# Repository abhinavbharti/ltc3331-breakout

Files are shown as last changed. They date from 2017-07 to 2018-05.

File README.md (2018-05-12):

## Open, low-cost experimentation board for the LTC3331 energy harvesting chip
	
This project contains design- and production-files for a
low-cost LTC3331 energy harvesting development-, breakout- and test-board.

It's specifically designed to be inexpensive, yet open and comprehensive:
* Full design files for KiCad EDA
* 10cm x 10cm PCB with 2 layers
* Full pin breakout
* Less-comprehensive headers for pins usually required
* LIR2032 holder and alternative battery port
* All default options can be jumpered on or off
* Supercap pads provided

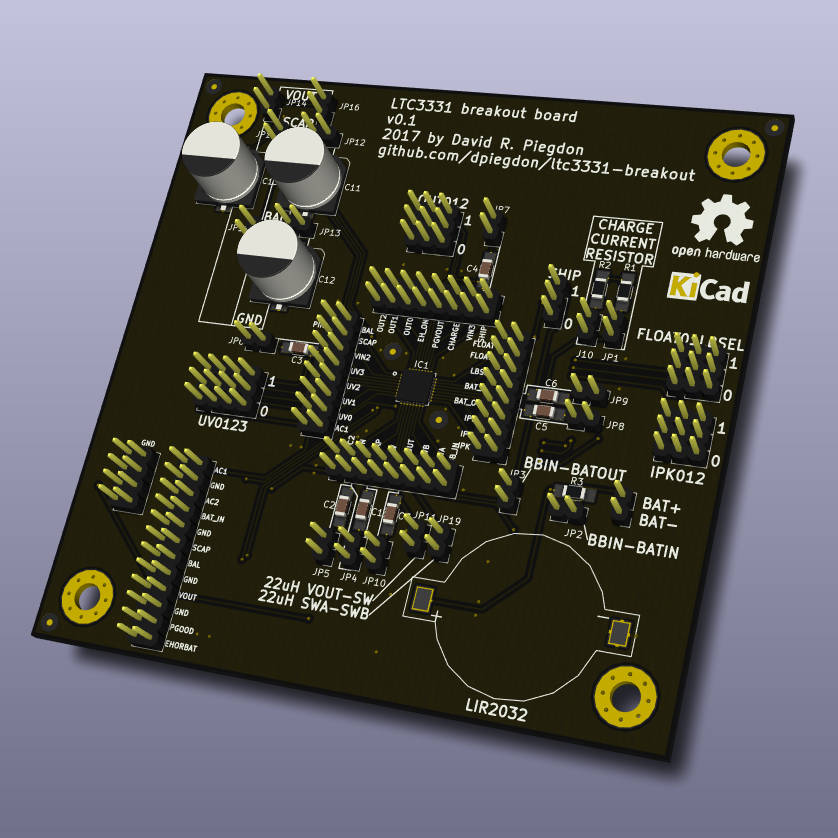
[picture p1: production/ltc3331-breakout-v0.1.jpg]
PCB v0.1 rendering from KiCad


(Above: v0.1, image rendered by KiCad EDA)

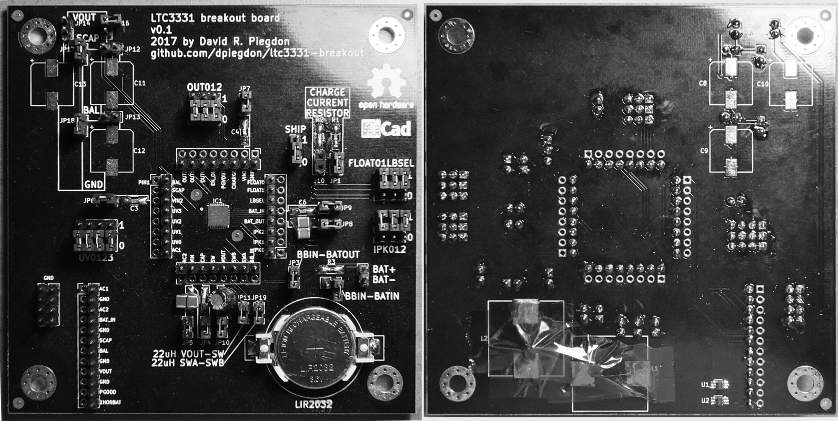
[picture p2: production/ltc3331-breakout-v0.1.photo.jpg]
PCB v0.1 photo


(Above: v0.1, actual photo of both sides)

## Releases and History

All production files for releases can be found in the
production/ directory. All required production files for
PCB production should be zipped in a way that allows immediate upload
to your preferred online PCB manufacturer.

v0.1 is the first version of the PCB. It has a few minor issues
(see Errata), but is fine for testing.

## Errata

### v0.1

v0.1 works fine, but there are a few issues that should be
addressed for another release:

Schematic:

* jumper for BBIN-BATIN connection is not needed.

* scatter more GND connectors for oscilloscope use

* maybe provide circuit for higher current charging,
  as seen in datasheet figure 7, pg 27?

* extra small header for GND/AC1/AC2/VIN

Footprints:

* footprints for 22uF inductors on bottom layer are way too large.
  a Taiyo-Yuden NR-30xx handsoldering footprint would be fine and should
  be moved to the front side. then there would be no components on the bottom.

* replace all capacitance footprints >= 10uF with larger
  footprint for e.g. tantalum capacitor.

* make cap footprints dual-use: through-hole AND smd?

PCB Placement / Routing:

* reorder all selection jumpers so they comply the the datasheet table

Silkscreen:

* mark down input voltage limits (3-19V)

* add white box for charge-current-resistor value placed by user

* if enough place, print cap values (and voltage ratings?)

Other:

* pdf schematic was missing in release files (was added later).
  next release should contain that immediately.

## Prior Art and Alternatives

Please note: personally I did not obtain any of the following
alternatives, so any comparison is a rough guess.

DC2151A is the de-facto standard demo- and dev-board that
Linear Technology created for this chip.
However, it's really expensive. (200+ €/$)

The "LTC3331 Energy Harvester, DC Converter and Charger"
by Blue Spark Labs is a much cheaper alternative to the
official dev-board.
But it seemingly does not offer comprehensive access to all pins
and full breakout options. Also, worldwide shipping can be
quite expensive, it seems.

## Use

When you want to use or modify the design in KiCad, you should get used
to handling git-submodules. I keep my custom footprints and symbols in
a separate repository so I can re-use them.

Have fun!

## Feedback

If you have design improvements, find it useful or stupid, or
want to let me know anything else, just let me know ;).

## License, copyright

The design is released under the OSHW 1.0 license as defined
by [https://www.oshwa.org/definition/].

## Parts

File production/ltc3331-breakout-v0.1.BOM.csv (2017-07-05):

Id | Designator | Package | Quantity | Designation | Supplier and ref
1 | C7 | C_1206_HandSoldering | 1 | 150uF 6.3V
2 | JP15 | Pin_Header_Straight_1x03_Pitch2.54mm | 1 | Jumper_NC_Dual
3 | FID**,FID**,FID**,FID**,FID**,FID**,FID**,FID** | fiducial_i.5mm_o1.5mm | 8 | fiducial_i.5mm_o1.5mm
4 | REF**,REF**,REF**,REF** | MountingHole_4.3mm_M4_Pad_Via | 4 | MountingHole_4.3mm_M4_Pad_Via
5 | C12,C8,C9,C10,C11,C13 | CP_Elec_10x10 | 6 | DNP
6 | BT1 | SMTU-2032-LF | 1 | CR2032
7 | C1 | C_1206_HandSoldering | 1 | 1uF 6.3V
8 | C2 | C_1206_HandSoldering | 1 | 22uF 25V
9 | C3,C6 | C_1206_HandSoldering | 2 | 4.7uF 6.3V
10 | C4 | C_1206_HandSoldering | 1 | 0.1uF 10V
11 | C5 | C_1206_HandSoldering | 1 | 22uF 6.3V
12 | IC1 | QFN-32-1EP_5x5mm_Pitch0.5mm | 1 | LTC3331
13 | J1,J6,J11 | Pin_Header_Straight_1x04_Pitch2.54mm | 3 | CONN_01X04
14 | J2,J3,J4,J7,J8,J9,J12,J13,J14 | Pin_Header_Straight_1x03_Pitch2.54mm | 9 | CONN_01X03
15 | J5 | Pin_Header_Straight_1x02_Pitch2.54mm | 1 | CONN_01X02
16 | J10 | Pin_Header_Straight_1x02_Pitch2.54mm | 1 | CONN_01X02_FEMALE
17 | J15 | Pin_Header_Straight_2x12_Pitch2.54mm | 1 | CONN_02X12
18 | J16,J17,J18,J19 | Pin_Header_Straight_2x08_Pitch2.54mm | 4 | CONN_02X08
19 | J20 | Pin_Header_Straight_2x04_Pitch2.54mm | 1 | CONN_02X04
20 | JP1,JP2,JP3,JP4,JP5,JP6,JP7,JP8,JP9,JP10,JP11,JP12,JP13,JP14,JP16,JP17,JP18,JP19 | Pin_Header_Straight_1x02_Pitch2.54mm | 18 | Jumper
21 | L1,L2 | Inductor_Wurth_HCI-1890 | 2 | 22uH
22 | R1 | R_1206_HandSoldering | 1 | 3K
23 | R2 | R_1206_HandSoldering | 1 | 10
24 | R3 | R_1206_HandSoldering | 1 | 100
25 | U1,U2 | SOT-363_SC-70-6_Handsoldering | 2 | NC7SZ58
26 | REF*** | OSHW-Logo2_14.6x12mm_SilkScreen | 1 | OSHW-Logo2_14.6x12mm_SilkScreen
27 | REF** | Symbol_KiCAD-Logo_CopperAndSilkScreenTop | 1 | KiCAD Logo

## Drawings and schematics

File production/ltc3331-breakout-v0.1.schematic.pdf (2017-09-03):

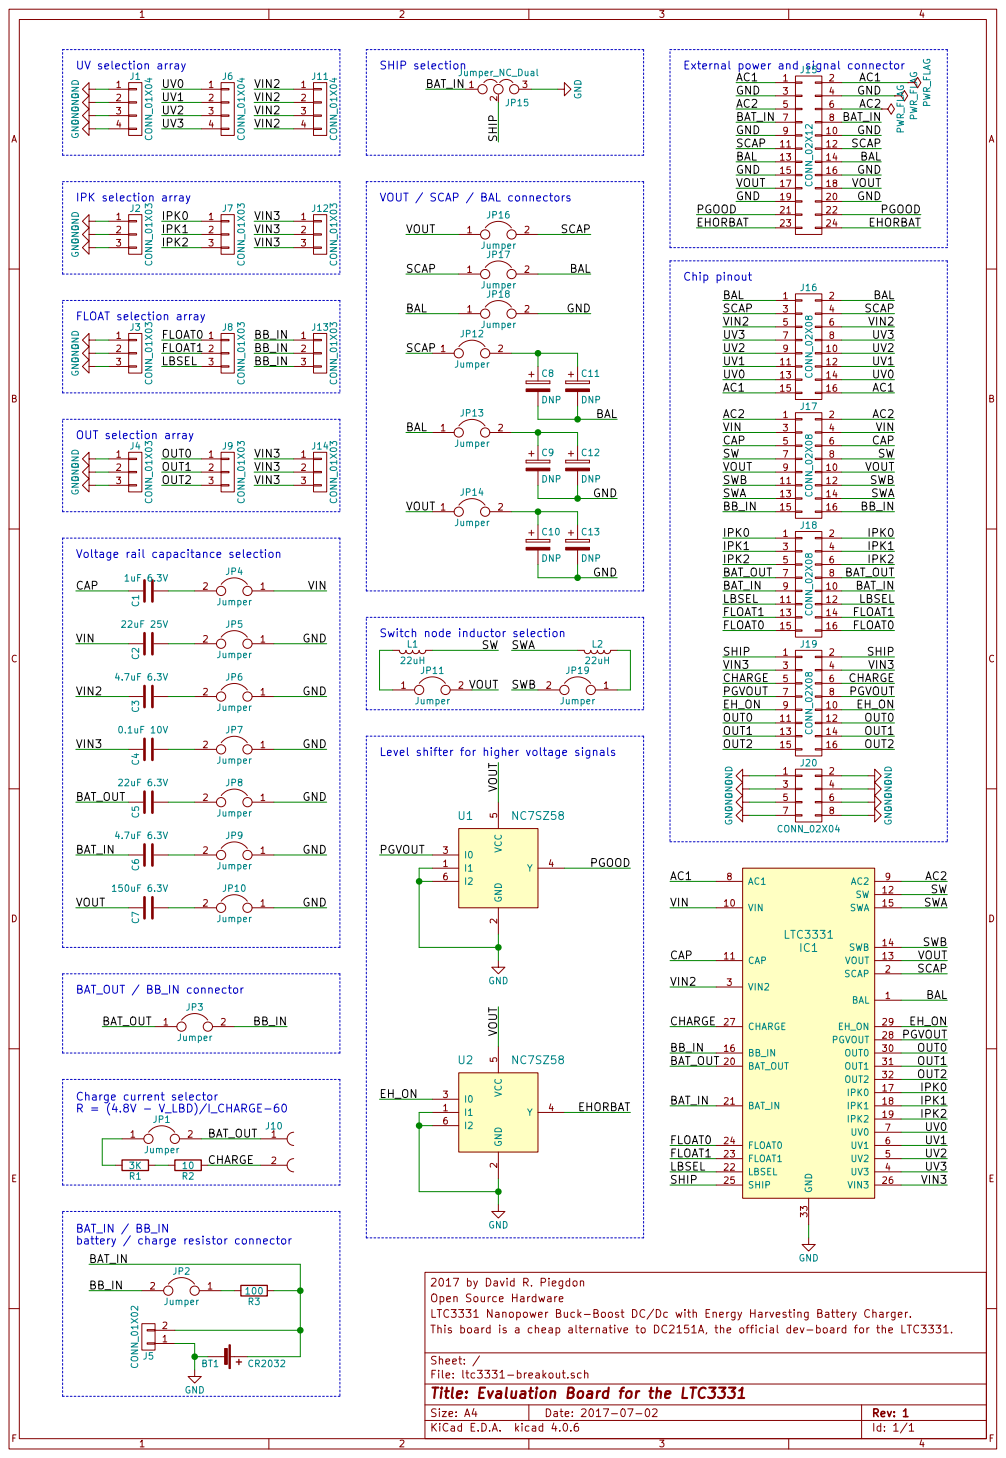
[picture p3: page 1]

External power and signal connector

Chip pinout BAL SCAP
VIN2 UV3 UV2 UV1 UV0 AC1

Voltage rail capacitance selection C5

IPK2 BAT_OUT | 5 | 6 | IPK2 BAT_OUT

Level shifter for higher voltage signals

Charge current selector JP1

FLOAT1

Open Source Hardware
LTC3331 Nanopower Buck-Boost DC/Dc with Energy Harvesting Battery Charger.
File: ltc3331-breakout.sch Sheet: / This board is a cheap alternative to DC2151A, the official dev-board for the LTC3331.

Id: 1/1 Title: Evaluation Board for the LTC3331

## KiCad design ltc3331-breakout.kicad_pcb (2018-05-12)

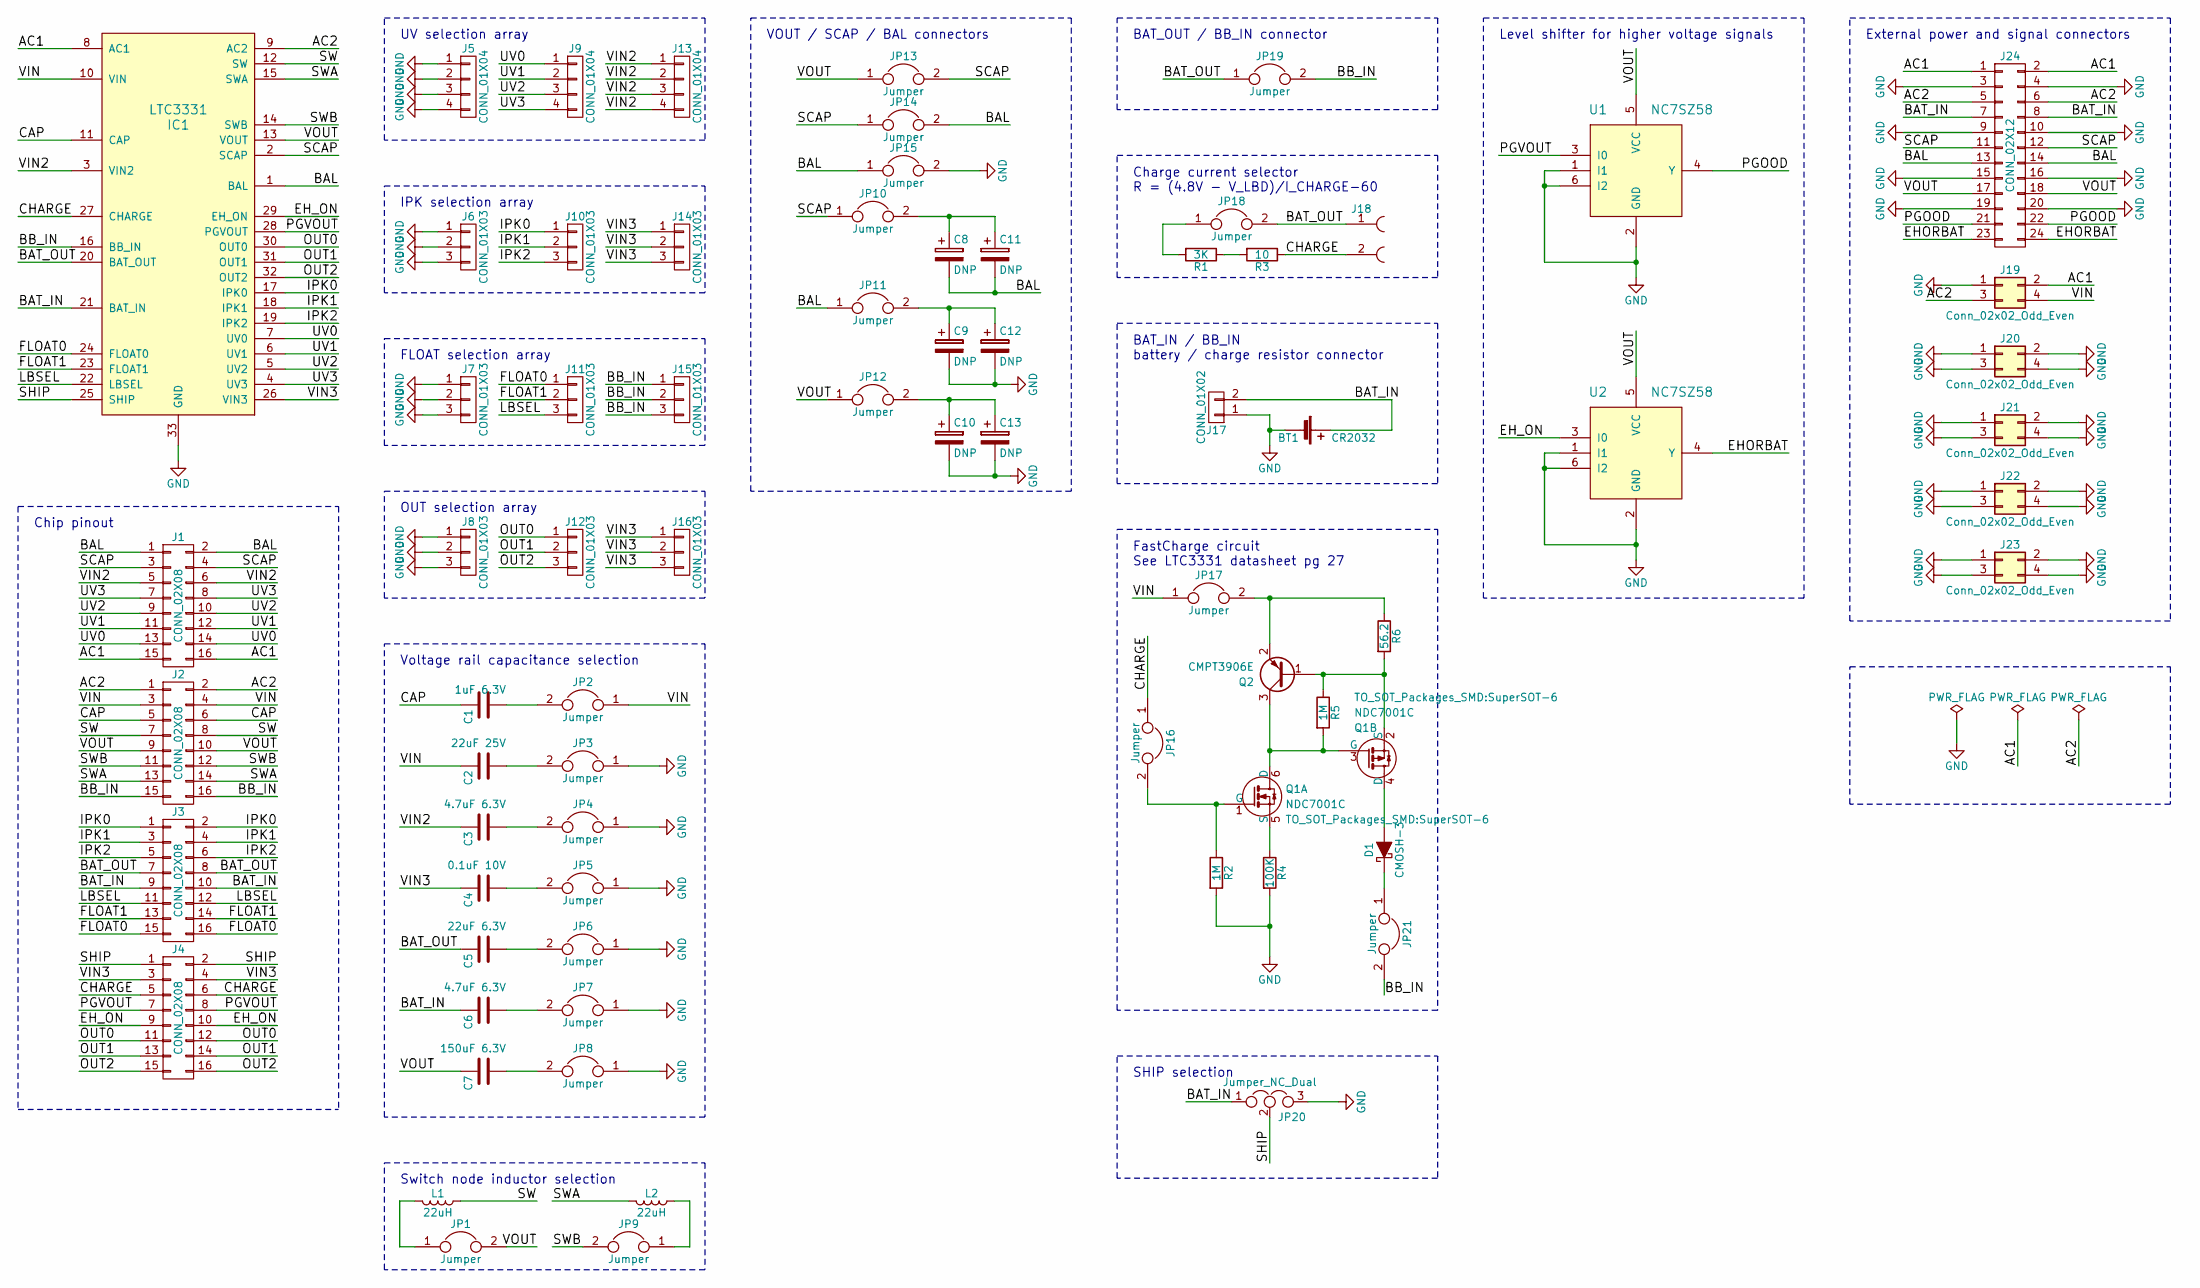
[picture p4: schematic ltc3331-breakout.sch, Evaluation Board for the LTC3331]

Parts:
BT1: CR2032; SMTU-2032-LF; Farnell 1216354
C1: 1uF 6.3V; C_1206_HandSoldering
C2: 22uF 25V; CAP_Generic_SMD_Radial_D10.0mm_P2.50mm_P5.00mm
C3, C6: 4.7uF 6.3V; CAP_Generic_SMD_Radial_D10.0mm_P2.50mm_P5.00mm
C4: 0.1uF 10V; C_1206_HandSoldering
C5: 22uF 6.3V; CAP_Generic_SMD_Radial_D10.0mm_P2.50mm_P5.00mm
C7: 150uF 6.3V; CAP_Generic_SMD_Radial_D10.0mm_P2.50mm_P5.00mm
C8, C9, C10, C11, C12, C13: DNP; CP_Elec_10x10
D1: CMOSH-3; D_SOD-523
IC1: LTC3331; QFN-32-1EP_5x5mm_Pitch0.5mm
J1, J2, J3, J4: CONN_02X08; Pin_Header_Straight_2x08_Pitch2.54mm
J5, J9, J13: CONN_01X04; Pin_Header_Straight_1x04_Pitch2.54mm
J6, J7, J8, J10, J11, J12, J14, J15, J16: CONN_01X03; Pin_Header_Straight_1x03_Pitch2.54mm
J17: CONN_01X02; Pin_Header_Straight_1x02_Pitch2.54mm
J18: CONN_01X02_FEMALE; Pin_Header_Straight_1x02_Pitch2.54mm
J19, J20, J21, J22, J23: Conn_02x02_Odd_Even; Pin_Header_Straight_2x02_Pitch2.54mm
J24: CONN_02X12; Pin_Header_Straight_2x12_Pitch2.54mm
JP1, JP2, JP3, JP4, JP5, JP6, JP7, JP8, JP9, JP10, JP11, JP12, JP13, JP14, JP15, JP16, JP17, JP18, JP19, JP21: Jumper; Pin_Header_Straight_1x02_Pitch2.54mm
JP20: Jumper_NC_Dual; Pin_Header_Straight_1x03_Pitch2.54mm
L1, L2: 22uH; Inductor_Taiyo-Yuden_NR-30xx_HandSoldering
Q1: NDC7001C; SuperSOT-6
Q2: CMPT3906E; SOT-23
R1: 3K; R_1206_HandSoldering
R2, R5: 1M; R_1206_HandSoldering
R3: 10; R_1206_HandSoldering
R4: 100K; R_1206_HandSoldering
R6: 56.2; R_1206_HandSoldering
U1, U2: NC7SZ58; SOT-363_SC-70-6_Handsoldering

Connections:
/AC1: IC1.8 (AC1), J1.15, J1.16, J19.2, J24.1, J24.2
/AC2: IC1.9 (AC2), J2.1, J2.2, J19.3, J24.5, J24.6
/BAL: C8.2, C11.2, IC1.1 (BAL), J1.1, J1.2, J24.13, J24.14, JP11.1, JP14.2, JP15.1
/BAT_IN: BT1.1 (+), C6.1, IC1.21 (BAT_IN), J3.9, J3.10, J17.2, J24.7, J24.8, JP20.1
/BAT_OUT: C5.1, IC1.20 (BAT_OUT), J3.7, J3.8, J18.1, JP18.2, JP19.1
/BB_IN: IC1.16 (BB_IN), J2.15, J2.16, J15.1, J15.2, J15.3, JP19.2, JP21.2
/CAP: C1.1, IC1.11 (CAP), J2.5, J2.6
/CHARGE: IC1.27 (CHARGE), J4.5, J4.6, J18.2, JP16.1, R3.1
/EHORBAT: J24.23, J24.24, U2.4 (Y)
/EH_ON: IC1.29 (EH_ON), J4.9, J4.10, U2.3 (I0)
/FLOAT0: IC1.24 (FLOAT0), J3.15, J3.16, J11.1
/FLOAT1: IC1.23 (FLOAT1), J3.13, J3.14, J11.2
/IPK0: IC1.17 (IPK0), J3.1, J3.2, J10.1
/IPK1: IC1.18 (IPK1), J3.3, J3.4, J10.2
/IPK2: IC1.19 (IPK2), J3.5, J3.6, J10.3
/LBSEL: IC1.22 (LBSEL), J3.11, J3.12, J11.3
/OUT0: IC1.30 (OUT0), J4.11, J4.12, J12.1
/OUT1: IC1.31 (OUT1), J4.13, J4.14, J12.2
/OUT2: IC1.32 (OUT2), J4.15, J4.16, J12.3
/PGOOD: J24.21, J24.22, U1.4 (Y)
/PGVOUT: IC1.28 (PGVOUT), J4.7, J4.8, U1.3 (I0)
/SCAP: IC1.2 (SCAP), J1.3, J1.4, J24.11, J24.12, JP10.1, JP13.2, JP14.1
/SHIP: IC1.25 (SHIP), J4.1, J4.2, JP20.2
/SW: IC1.12 (SW), J2.7, J2.8, L1.1
/SWA: IC1.15 (SWA), J2.13, J2.14, L2.1
/SWB: IC1.14 (SWB), J2.11, J2.12, JP9.2
/UV0: IC1.7 (UV0), J1.13, J1.14, J9.1
/UV1: IC1.6 (UV1), J1.11, J1.12, J9.2
/UV2: IC1.5 (UV2), J1.9, J1.10, J9.3
/UV3: IC1.4 (UV3), J1.7, J1.8, J9.4
/VIN: C2.1, IC1.10 (VIN), J2.3, J2.4, J19.4, JP2.1, JP17.1
/VIN2: C3.1, IC1.3 (VIN2), J1.5, J1.6, J13.1, J13.2, J13.3, J13.4
/VIN3: C4.1, IC1.26 (VIN3), J4.3, J4.4, J14.1, J14.2, J14.3, J16.1, J16.2, J16.3
/VOUT: C7.1, IC1.13 (VOUT), J2.9, J2.10, J24.17, J24.18, JP1.2, JP12.1, JP13.1, U1.5 (VCC), U2.5 (VCC)
GND: BT1.2 (-), C9.2, C10.2, C12.2, C13.2, IC1.33 (GND), J5.1, J5.2, J5.3, J5.4, J6.1, J6.2, J6.3, J7.1, J7.2, J7.3, J8.1, J8.2, J8.3, J17.1, J19.1, J20.1, J20.2, J20.3, J20.4, J21.1, J21.2, J21.3, J21.4, J22.1, J22.2, J22.3, J22.4, J23.1, J23.2, J23.3, J23.4, J24.3, J24.4, J24.9, J24.10, J24.15, J24.16, J24.19, J24.20, JP3.1, JP4.1, JP5.1, JP6.1, JP7.1, JP8.1, JP15.2, JP20.3, R2.2, R4.2, U1.1 (I1), U1.2 (GND), U1.6 (I2), U2.1 (I1), U2.2 (GND), U2.6 (I2)
unnamed: C1.2, JP2.2
unnamed: C2.2, JP3.2
unnamed: C3.2, JP4.2
unnamed: C4.2, JP5.2
unnamed: C5.2, JP6.2
unnamed: C6.2, JP7.2
unnamed: C7.2, JP8.2
unnamed: C10.1, C13.1, JP12.2
unnamed: C8.1, C11.1, JP10.2
unnamed: C9.1, C12.1, JP11.2
unnamed: D1.1 (K), JP21.1
unnamed: D1.2 (A), Q1.4 (D)
unnamed: JP1.1, L1.2
unnamed: JP9.1, L2.2
unnamed: JP16.2, Q1.1 (G), R2.1
unnamed: JP17.2, Q2.2 (E), R6.1
unnamed: JP18.1, R1.2
unnamed: Q1.2 (S), Q2.1 (B), R5.1, R6.2
unnamed: Q1.3 (G), Q1.6 (D), Q2.3 (C), R5.2
unnamed: Q1.5 (S), R4.1
unnamed: R1.1, R3.2

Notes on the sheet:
OUT selection array
IPK selection array
UV selection array
FLOAT selection array
SHIP selection
Charge current selector R = (4.8V - V_LBD)/I_CHARGE-60
BAT_OUT / BB_IN connector
Switch node inductor selection
Chip pinout
Voltage rail capacitance selection
BAT_IN / BB_IN battery / charge resistor connector
VOUT / SCAP / BAL connectors
External power and signal connectors
Level shifter for higher voltage signals
FastCharge circuit See LTC3331 datasheet pg 27

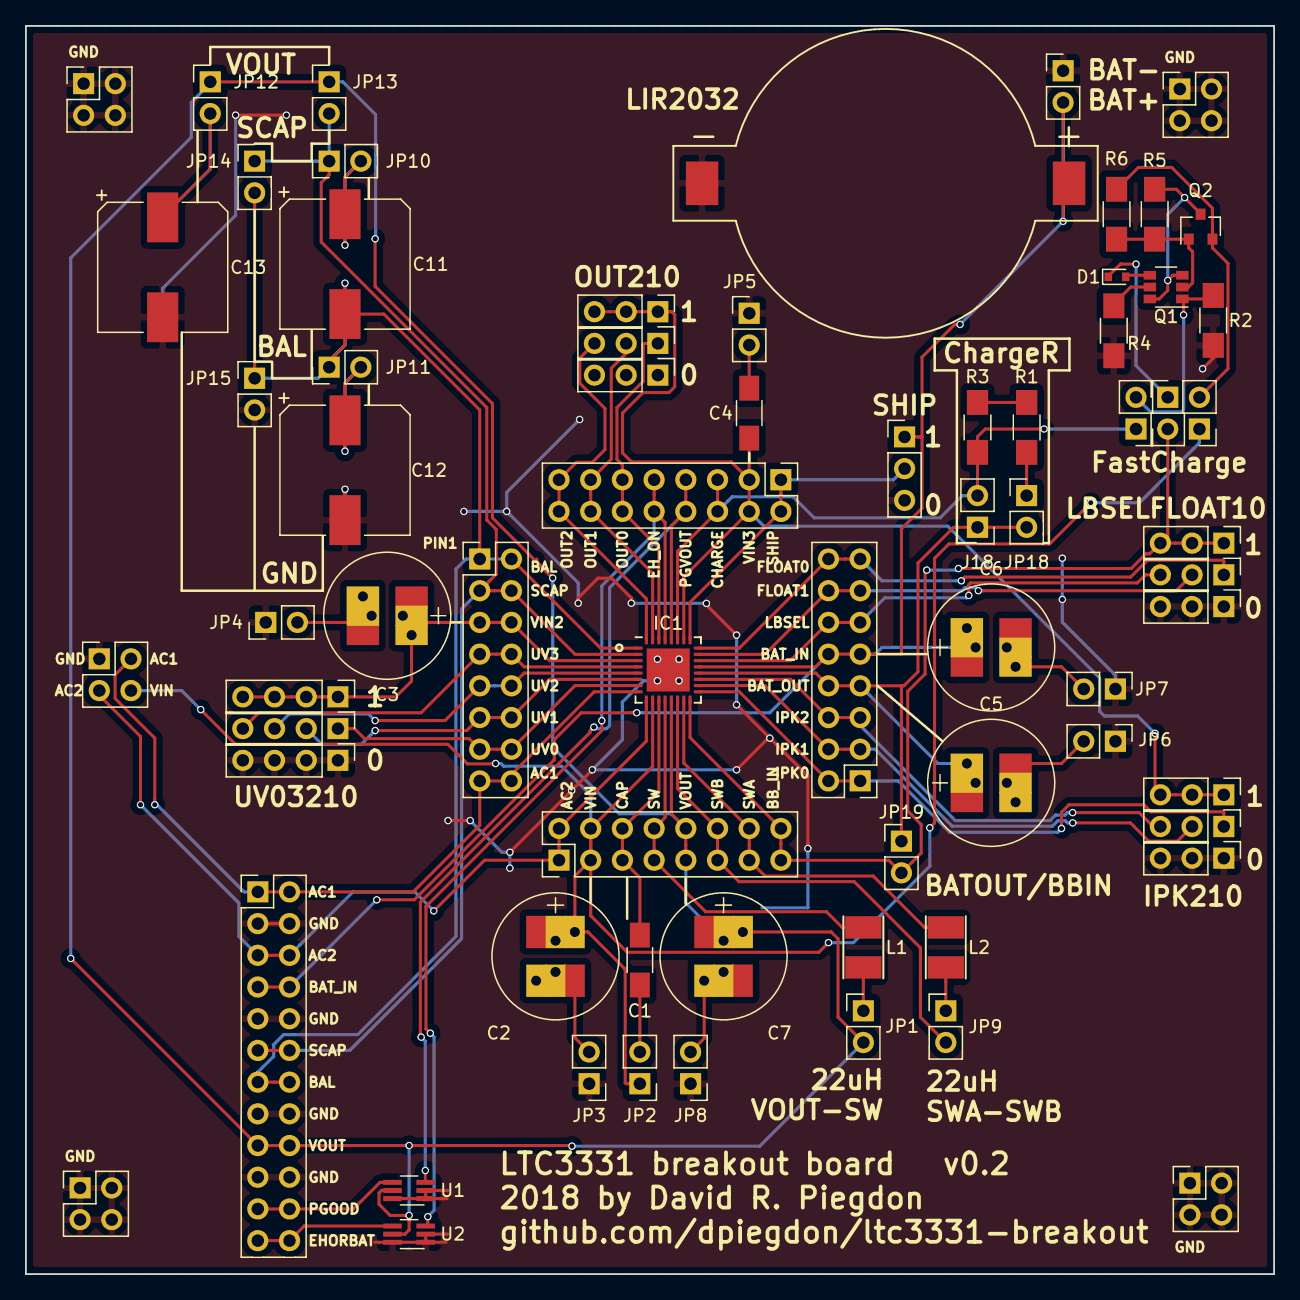
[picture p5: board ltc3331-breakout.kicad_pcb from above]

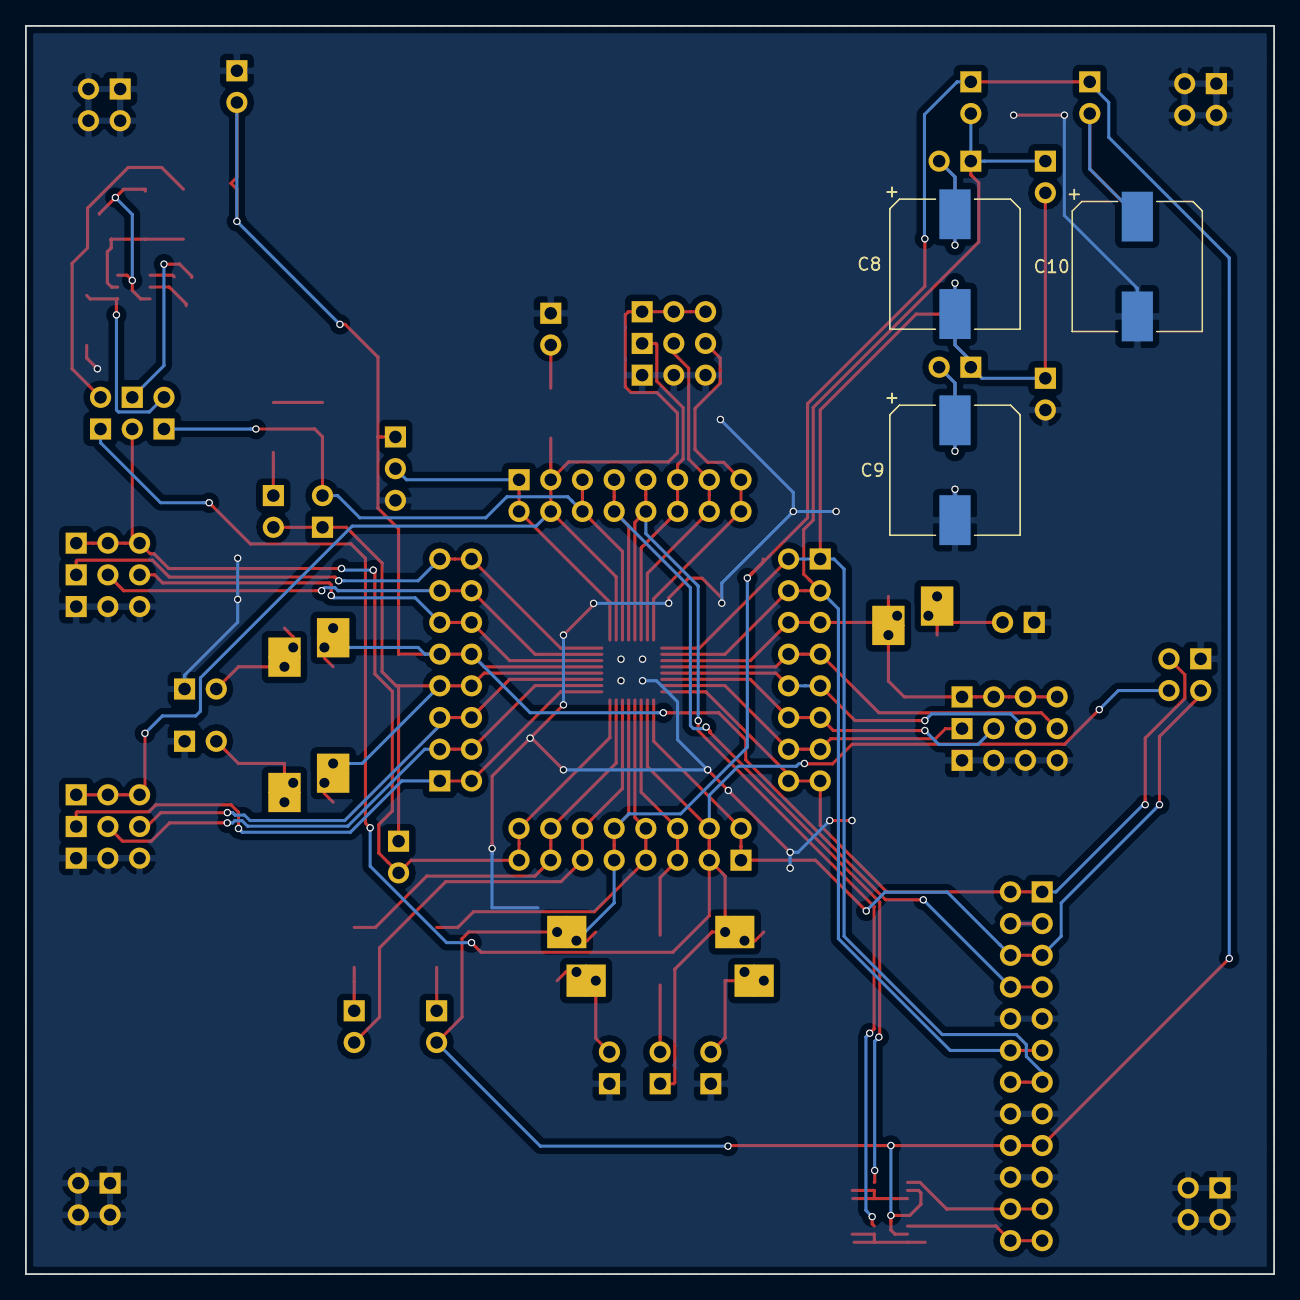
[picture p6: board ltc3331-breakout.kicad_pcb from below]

Board: 2 copper layers, 100.0 x 100.0 mm, 73 parts (3 on the bottom side), 56 nets.

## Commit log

2017-07-04 initial setup with library
    [ltc3331-breakout.kicad_pcb, ltc3331-breakout.sch]
2017-07-04 initial, preliminary version
    [ltc3331-breakout.sch]
2017-07-04 schematic cleanup
    [ltc3331-breakout.sch]
2017-07-04 added level shifter for PGOOD, EHORBAT; cleanup; most footprints
    [ltc3331-breakout.sch]
2017-07-04 use lipo-connector instead of CR2477. cleanup.
    [ltc3331-breakout.sch]
2017-07-05 basic routing and silk screen. verification pending.
    [ltc3331-breakout.kicad_pcb]
2017-07-05 routing cleanup, copper pour cleanup, added mounting holes and more silk screen labels
    [ltc3331-breakout.kicad_pcb]
2017-07-05 fixed silkscreen bug, layout cleanup, production stuff
    [ltc3331-breakout.kicad_pcb]
2017-07-05 more cleanup
    [ltc3331-breakout.kicad_pcb]
2017-07-05 finished v0.1 production files
    [ltc3331-breakout-v0.1.BOM.csv, ltc3331-breakout.kicad_pcb]
2017-07-11 README and rendering of PCB
2017-09-06 replace 22uF inductor footprints with better ones
    [ltc3331-breakout.kicad_pcb, ltc3331-breakout.sch]
2017-09-06 move U1,U2 to front side to clear rear side of all required components.
    [ltc3331-breakout.kicad_pcb]
2018-05-12 schematic: applied some errata from v0.1
    [ltc3331-breakout.sch]
2018-05-12 routed changes
    [ltc3331-breakout.kicad_pcb, ltc3331-breakout.sch]
2018-05-12 added footprints
2018-05-12 replaced some capacitors with generic footprint, rerouted
    [ltc3331-breakout.kicad_pcb, ltc3331-breakout.sch]
